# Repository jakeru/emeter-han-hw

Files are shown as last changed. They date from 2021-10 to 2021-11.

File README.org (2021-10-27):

#+TITLE: Use HAN port to get electricity usage

This is a software engineer playing with KiCad.

I have tried a few approaches but the one that is now active is the
e-meter-han-usb-c variant. It consists of a ESP32 and a USB-C connector as well
as a connector for the HAN port.

Note that this is still work in progress!

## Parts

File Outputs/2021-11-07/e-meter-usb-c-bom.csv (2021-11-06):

Comment | Designator | Footprint | LCSC Part #
10u Unpolarized capacitor | C1 | C_0603_1608Metric_Pad1.08x0.95mm_HandSolder | C19702
470p Unpolarized capacitor | C2 | C_0603_1608Metric_Pad1.08x0.95mm_HandSolder | C1620
2.2u Unpolarized capacitor | C3 | C_0603_1608Metric_Pad1.08x0.95mm_HandSolder | C23630
0.1u Unpolarized capacitor | C4,C6,C7 | C_0603_1608Metric_Pad1.08x0.95mm_HandSolder | C14663
22u Unpolarized capacitor | C5 | C_0603_1608Metric_Pad1.08x0.95mm_HandSolder | C59461
MDD-SS14 40V 1A Schottky Barrier Rectifier Diode, SMA(DO-214AC) | D1,D2 | D_SMA | C2480
LED Light emitting diode | D3,D4,D5 | LED_0603_1608Metric_Pad1.05x0.95mm_HandSolder | C2290
6P6C RJ connector, 6P6C (6 positions 6 connected), RJ12/RJ18/RJ25 | J1 | RJ12_Amphenol_54601 | C305981
USB_C_Receptacle_USB2.0 USB 2.0-only Type-C Receptacle connector | J2 | USB_C_Receptacle_HRO_TYPE-C-31-M-12 | C165948
S8050 0.7A Ic, 20V Vce, Low Voltage High Current NPN Transistor, TO-92 | Q1,Q3,Q4 | SOT-23 | C2150
4.7k Resistor, US symbol | R2 | R_0603_1608Metric_Pad0.98x0.95mm_HandSolder | C23162
68 Resistor, US symbol | R3,R7,R11 | R_0603_1608Metric_Pad0.98x0.95mm_HandSolder | C27592
10k Resistor, US symbol | R4,R5,R6,R10 | R_0603_1608Metric_Pad0.98x0.95mm_HandSolder | C25804
5.6k Resistor, US symbol | R8,R9 | R_0603_1608Metric_Pad0.98x0.95mm_HandSolder | C23189
SW_Push Push button switch, generic, two pins | SW1 | TE_Connectivity_FSM2JSMAA | C127509
ESP32-WROOM-32 RF Module, ESP32-D0WDQ6 SoC, Wi-Fi 802.11b/g/n, Bluetooth, BLE, 32-bit, 2.7-3.6V, onboard antenna, SMD | U2 | ESP32-WROOM-32 | C82899
CH340B (or C) USB serial converter, UART, SOIC-16 | U4 | SOIC-16_3.9x9.9mm_P1.27mm | C81010

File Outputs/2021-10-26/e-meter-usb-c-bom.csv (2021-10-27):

Comment | Designator | Footprint | LCSC Part #
10u Unpolarized capacitor | C1 | C_0603_1608Metric_Pad1.08x0.95mm_HandSolder
470p Unpolarized capacitor | C2 | C_0603_1608Metric_Pad1.08x0.95mm_HandSolder
2.2u Unpolarized capacitor | C3 | C_0603_1608Metric_Pad1.08x0.95mm_HandSolder
0.1u Unpolarized capacitor | C4,C6,C7 | C_0603_1608Metric_Pad1.08x0.95mm_HandSolder
22u Unpolarized capacitor | C5 | C_0603_1608Metric_Pad1.08x0.95mm_HandSolder
MDD-SS14 40V 1A Schottky Barrier Rectifier Diode, SMA(DO-214AC) | D1,D2 | D_SMA | C2480
LED Light emitting diode | D3,D4,D5 | LED_0201_0603Metric_Pad0.64x0.40mm_HandSolder | C2290
6P6C RJ connector, 6P6C (6 positions 6 connected), RJ12/RJ18/RJ25 | J1 | RJ12_Amphenol_54601 | C305981
USB_C_Receptacle_USB2.0 USB 2.0-only Type-C Receptacle connector | J2 | USB_C_Receptacle_HRO_TYPE-C-31-M-12 | C165948
S8050 0.7A Ic, 20V Vce, Low Voltage High Current NPN Transistor, TO-92 | Q1,Q3,Q4 | SOT-23 | C2150
4.7k Resistor, US symbol | R2 | R_0201_0603Metric_Pad0.64x0.40mm_HandSolder
60 Resistor, US symbol | R3,R7,R11 | R_0201_0603Metric_Pad0.64x0.40mm_HandSolder
10k Resistor, US symbol | R4,R5,R6,R10 | R_0201_0603Metric_Pad0.64x0.40mm_HandSolder
5.6k Resistor, US symbol | R8,R9 | R_0201_0603Metric_Pad0.64x0.40mm_HandSolder
SW_Push Push button switch, generic, two pins | SW1 | TE_Connectivity_FSM2JSMAA | C127509
ESP32-WROOM-32 RF Module, ESP32-D0WDQ6 SoC, Wi-Fi 802.11b/g/n, Bluetooth, BLE, 32-bit, 2.7-3.6V, onboard antenna, SMD | U2 | ESP32-WROOM-32 | C82899
CH340B (or C) USB serial converter, UART, SOIC-16 | U4 | SOIC-16_3.9x9.9mm_P1.27mm | C81010

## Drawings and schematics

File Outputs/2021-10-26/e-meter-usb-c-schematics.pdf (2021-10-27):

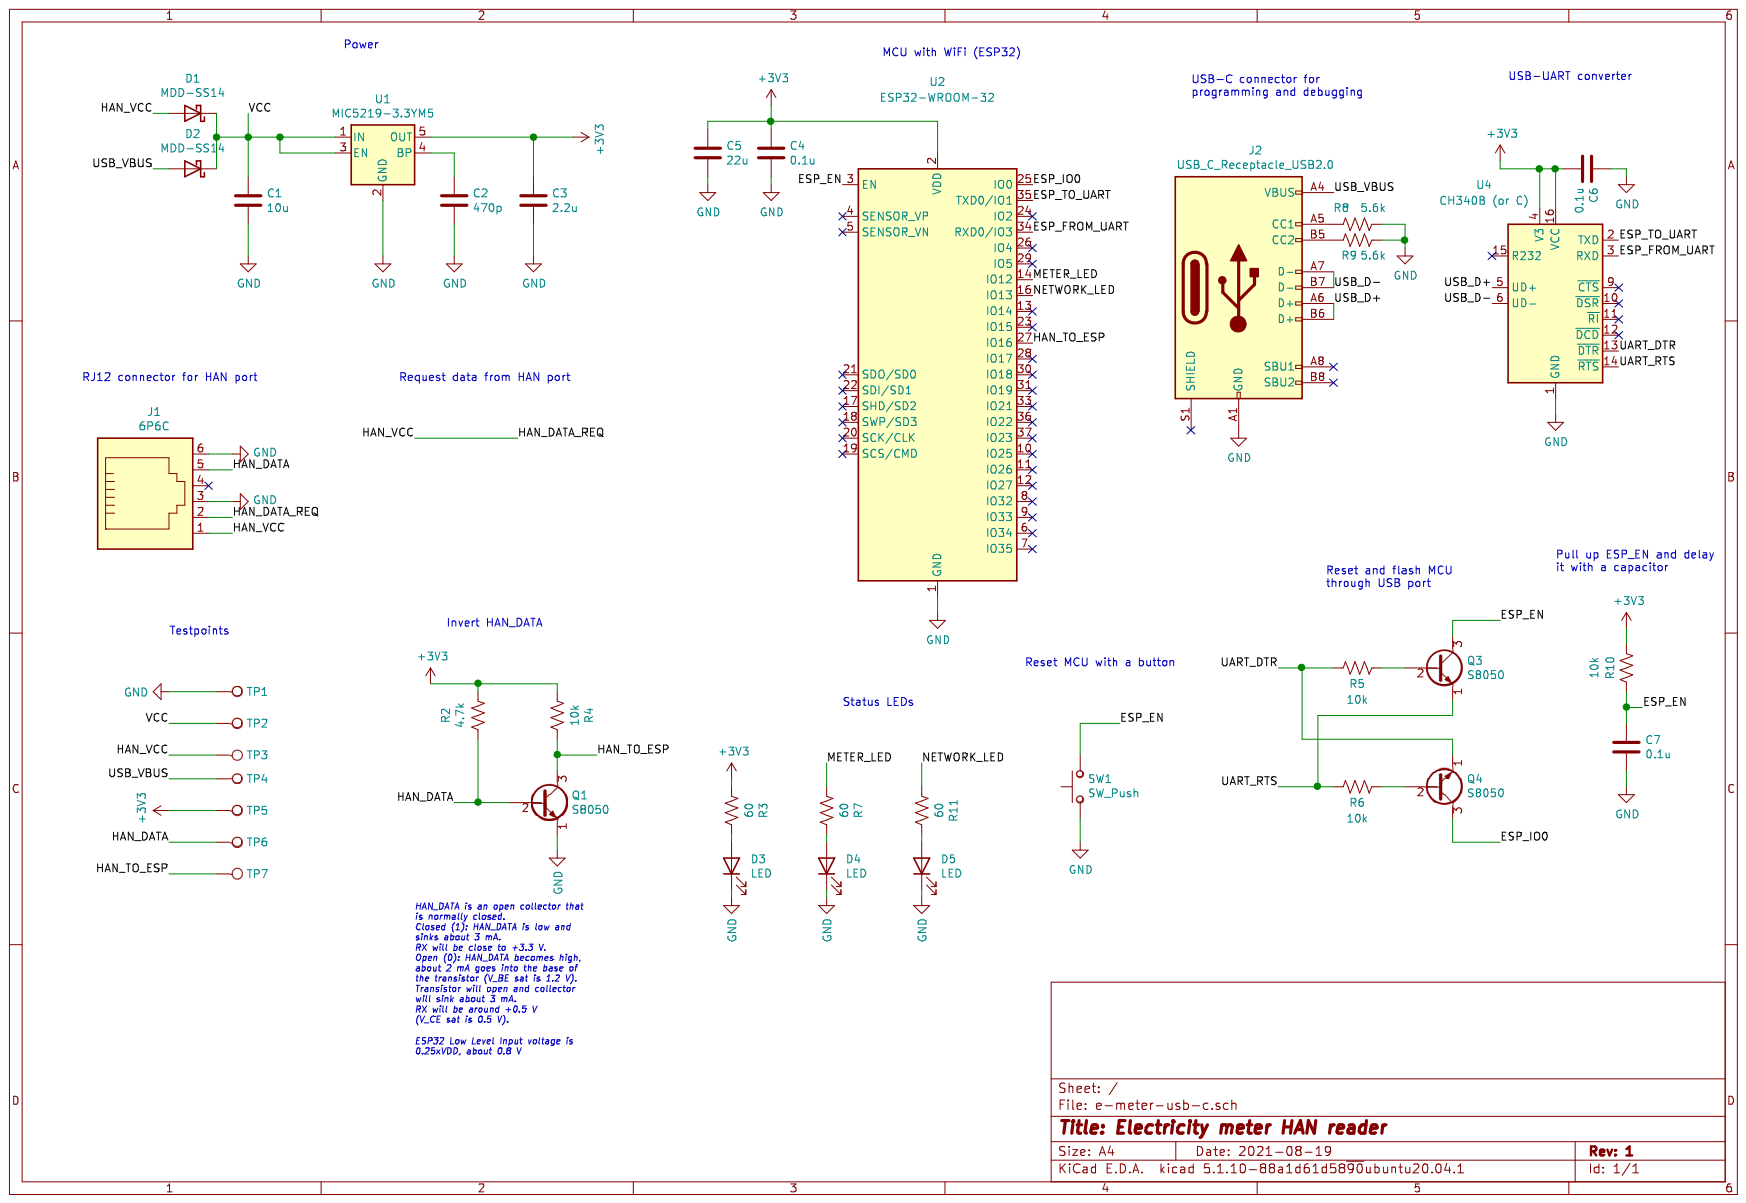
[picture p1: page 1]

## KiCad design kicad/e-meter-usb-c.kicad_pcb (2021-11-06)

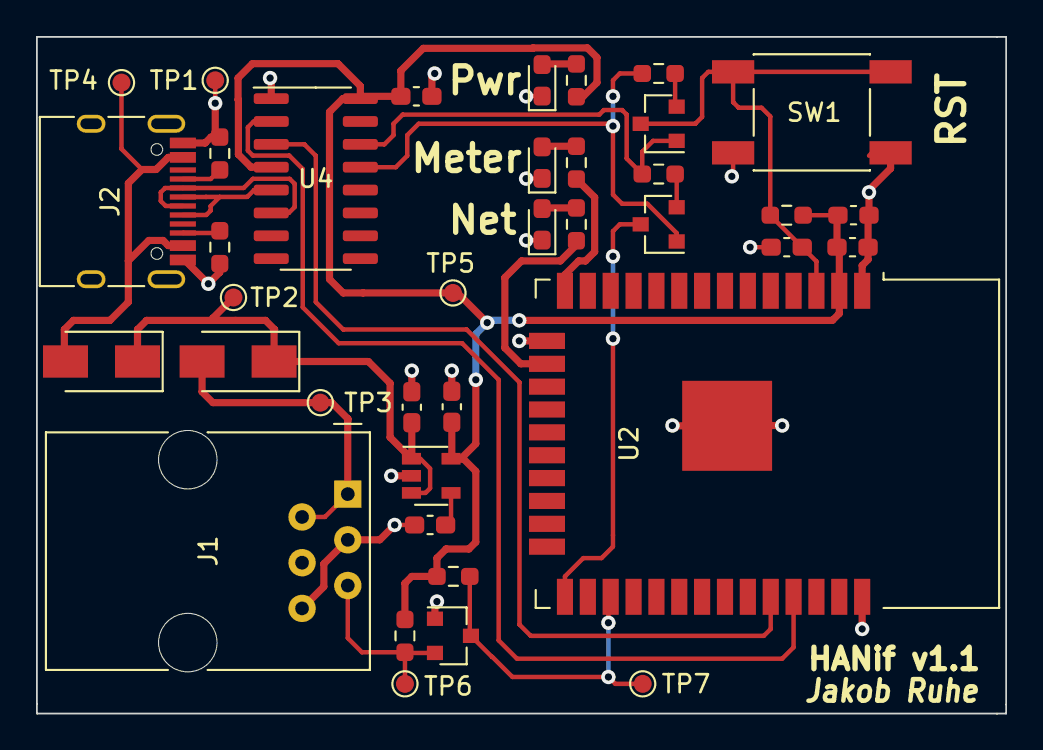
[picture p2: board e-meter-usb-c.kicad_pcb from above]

Board: 2 copper layers, 53.8 x 37.6 mm, 38 parts (0 on the bottom side), 25 nets.

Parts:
C1: 10u; C_0603_1608Metric_Pad1.08x0.95mm_HandSolder
C2: 470p; C_0603_1608Metric_Pad1.08x0.95mm_HandSolder
C3: 2.2u; C_0603_1608Metric_Pad1.08x0.95mm_HandSolder
C4, C6, C7: 0.1u; C_0603_1608Metric_Pad1.08x0.95mm_HandSolder
C5: 22u; C_0603_1608Metric_Pad1.08x0.95mm_HandSolder
D1, D2: MDD-SS14; D_SMA
D3, D4, D5: LED; LED_0603_1608Metric_Pad1.05x0.95mm_HandSolder
J1: 6P6C; RJ12_Amphenol_54601
J2: USB_C_Receptacle_USB2.0; USB_C_Receptacle_HRO_TYPE-C-31-M-12
Q1, Q3, Q4: S8050; SOT-23
R2: 4.7k; R_0603_1608Metric_Pad0.98x0.95mm_HandSolder
R3, R7, R11: 68; R_0603_1608Metric_Pad0.98x0.95mm_HandSolder
R4, R5, R6, R10: 10k; R_0603_1608Metric_Pad0.98x0.95mm_HandSolder
R8, R9: 5.6k; R_0603_1608Metric_Pad0.98x0.95mm_HandSolder
SW1: SW_Push; TE_Connectivity_FSM2JSMAA
TP1, TP2, TP3, TP4, TP5, TP6, TP7: TestPoint; TestPoint_Pad_D1.0mm
U1: MIC5219-3.3YM5; SOT-23-5
U2: ESP32-WROOM-32
U4: CH340B (or C); SOIC-16_3.9x9.9mm_P1.27mm

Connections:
+3V3: C3.1, C4.1, C5.1, C6.2, R2.1, R3.2, R4.2, R10.2, TP5.1, U1.5, U2.2, U4.4, U4.16
/ESP_EN: C7.1, Q3.3, R10.1, SW1.1, U2.3
/ESP_FROM_UART: U2.34, U4.3
/ESP_IO0: Q4.3, U2.25
/ESP_TO_UART: U2.35, U4.2
/HAN_DATA: J1.5, Q1.2, R2.2, TP6.1
/HAN_DATA_REQ: D1.2, J1.1, J1.2, TP3.1
/HAN_TO_ESP: Q1.3, R4.1, TP7.1, U2.27
/METER_LED: R7.2, U2.14
/NETWORK_LED: R11.2, U2.16
/UART_DTR: Q4.1, R5.2, U4.13
/UART_RTS: Q3.1, R6.2, U4.14
/USB_D+: J2.A6, J2.B6, U4.5
/USB_D-: J2.A7, J2.B7, U4.6
/USB_VBUS: D2.2, J2.A4, J2.A9, J2.B4, J2.B9, TP4.1
GND: C1.2, C2.2, C3.2, C4.2, C5.2, C6.1, C7.2, D3.1, D4.1, D5.1, J1.3, J1.6, J2.A1, J2.A12, J2.B1, J2.B12, Q1.1, R8.2, R9.2, SW1.2, TP1.1, U1.2, U2.1, U2.15, U2.38, U2.39, U4.1
unnamed: C2.1, U1.4
unnamed: D3.2, R3.1
unnamed: D4.2, R7.1
unnamed: D5.2, R11.1
unnamed: J2.A5, R8.1
unnamed: J2.B5, R9.1
unnamed: Q3.2, R5.1
unnamed: Q4.2, R6.1
VCC: C1.1, D1.1, D2.1, TP2.1, U1.1, U1.3

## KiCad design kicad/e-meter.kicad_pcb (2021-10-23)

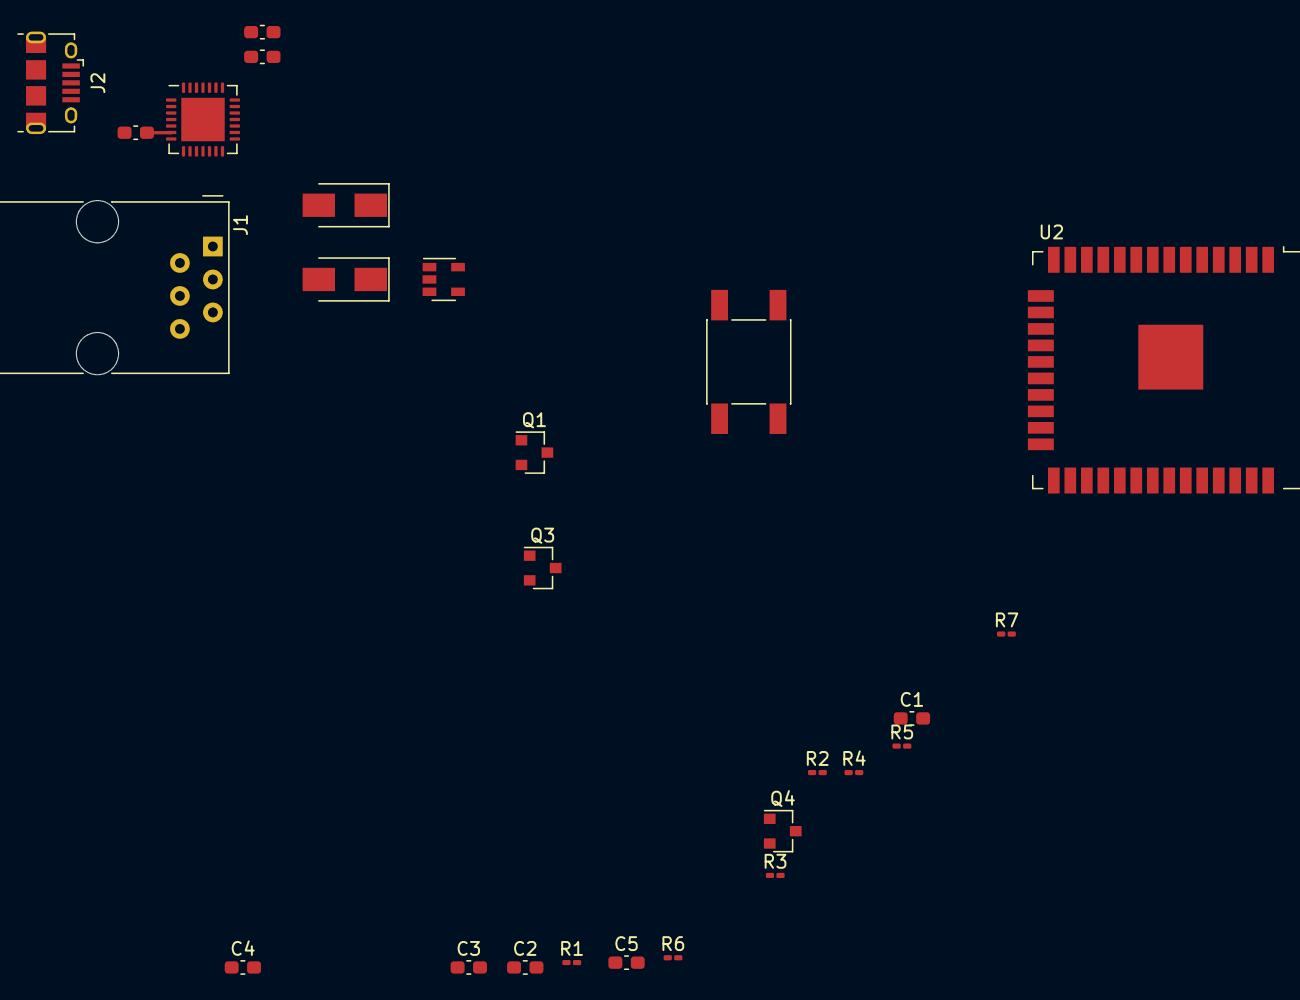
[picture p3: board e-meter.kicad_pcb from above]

Board: 2 copper layers, 26 parts (0 on the bottom side), 20 nets.

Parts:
C1, C2: 10u; C_0603_1608Metric_Pad1.08x0.95mm_HandSolder
C3, C5, C6: 1u; C_0603_1608Metric_Pad1.08x0.95mm_HandSolder
C4: 22u; C_0603_1608Metric_Pad1.08x0.95mm_HandSolder
C7, C8: 0.1u; C_0603_1608Metric_Pad1.08x0.95mm_HandSolder
D1, D2: MDD-SS14; D_SMA
J1: 6P6C; RJ12_Amphenol_54601
J2: USB_B_Micro; USB_Micro-B_Amphenol_10118194_Horizontal
Q1, Q3, Q4: S8050; SOT-23
R1: 100K; R_0201_0603Metric_Pad0.64x0.40mm_HandSolder
R2, R3, R4: 1K; R_0201_0603Metric_Pad0.64x0.40mm_HandSolder
R5, R6: 10k; R_0201_0603Metric_Pad0.64x0.40mm_HandSolder
R7: 10K; R_0201_0603Metric_Pad0.64x0.40mm_HandSolder
SW1: SW_Push; TE_Connectivity_FSM2JSMAA
U1: AP2112K-3.3; SOT-23-5
U2: ESP32-WROOM-32
U3: CP2102N-A01-GQFN28; QFN-28-1EP_5x5mm_P0.5mm_EP3.35x3.35mm

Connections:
+3V3: C2.1, C3.1, C4.1, R2.1, R4.2, R7.1, U1.5, U2.2
/CP_DTR: Q4.1, R5.2, U3.28
/CP_REGIN: C6.1, C8.1, D2.2, J2.1, U3.7, U3.8
/CP_RTS: Q3.1, R6.2, U3.24
/CP_RXD: U2.35, U3.25
/CP_TXD: U2.34, U3.26
/CP_VDD: C7.2, U3.6
/EN: C5.1, Q3.3, R7.2, SW1.2, U2.3
/HAN_DATA: J1.5, Q1.2, R2.2
/HAN_DATA_REQ: J1.2, R3.1
/HAN_VCC: D1.2, J1.1, R3.2
/IO0: Q4.3, U2.25
/RX: Q1.3, R4.1
/USB_DM: J2.2, U3.5
/USB_DP: J2.3, U3.4
/VCC: C1.1, D1.1, D2.1, R1.2, U1.1
GND: C1.2, C2.2, C3.2, C4.2, C5.2, C6.2, C7.1, C8.2, J1.3, J1.6, J2.5, Q1.1, SW1.1, U1.2, U2.1, U2.15, U2.38, U2.39, U3.3, U3.29
unnamed: Q3.2, R5.1
unnamed: Q4.2, R6.1
unnamed: R1.1, U1.3

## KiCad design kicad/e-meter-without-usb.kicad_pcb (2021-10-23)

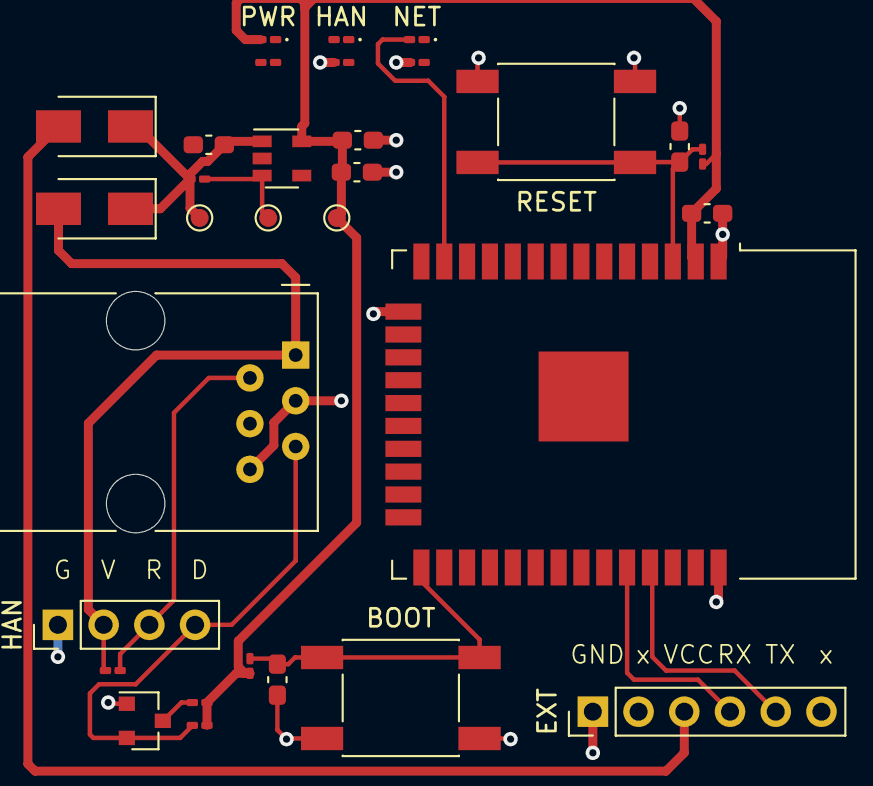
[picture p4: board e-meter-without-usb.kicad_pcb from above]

Board: 2 copper layers, 31 parts (0 on the bottom side), 18 nets.

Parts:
BOOT: SW_Push; TE_Connectivity_FSM2JSMAA
C1, C2: 10u; C_0603_1608Metric_Pad1.08x0.95mm_HandSolder
C3, C5, C6: 1u; C_0603_1608Metric_Pad1.08x0.95mm_HandSolder
C4: 22u; C_0603_1608Metric_Pad1.08x0.95mm_HandSolder
D1, D2: MDD-SS14; D_SMA
EXT: Conn_01x06; PinHeader_1x06_P2.54mm_Vertical
HAN: LED; LED_0201_0603Metric_Pad0.64x0.40mm_HandSolder
HAN#2: Conn_01x04; PinHeader_1x04_P2.54mm_Vertical
J1: 6P6C; RJ12_Amphenol_54601
NET: LED; LED_0201_0603Metric_Pad0.64x0.40mm_HandSolder
PWR: LED; LED_0201_0603Metric_Pad0.64x0.40mm_HandSolder
Q1: S8050; SOT-23
R1: 100K; R_0201_0603Metric_Pad0.64x0.40mm_HandSolder
R2, R3, R4: 1K; R_0201_0603Metric_Pad0.64x0.40mm_HandSolder
R5, R6, R9: 2K; R_0201_0603Metric_Pad0.64x0.40mm_HandSolder
R7, R8: 10K; R_0201_0603Metric_Pad0.64x0.40mm_HandSolder
RESET: SW_Push; TE_Connectivity_FSM2JSMAA
TP1, TP2, TP3: TestPoint; TestPoint_Pad_D1.0mm
U1: AP2112K-3.3; SOT-23-5
U2: ESP32-WROOM-32

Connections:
+3V3: C2.1, C3.1, C4.1, PWR.2, R2.1, R4.2, R7.1, R8.1, TP3.1, U1.5, U2.2
/BOOT: BOOT.2, C6.1, R8.2, U2.25
/EN: C5.1, R7.2, RESET.2, U2.3
/EXT_5V: D1.2, EXT.3
/EXT_FROM_ESP: EXT.5, U2.35
/EXT_TO_ESP: EXT.4, U2.34
/HAN_DATA: HAN#2.4, J1.5, Q1.2, R2.2
/HAN_DATA_REQ: HAN#2.3, J1.2, R3.1
/HAN_VCC: D2.2, HAN#2.2, J1.1, R3.2
/METER_LED: HAN.2, U2.23
/NETWORK_LED: NET.2, U2.13
/RX: Q1.3, R4.1
/VCC: C1.1, D1.1, D2.1, R1.2, TP1.1, U1.1
GND: BOOT.1, C1.2, C2.2, C3.2, C4.2, C5.2, C6.2, EXT.1, HAN#2.1, J1.3, J1.6, Q1.1, R5.1, R6.1, R9.1, RESET.1, U1.2, U2.1, U2.15, U2.38, U2.39
unnamed: PWR.1, R5.2
unnamed: NET.1, R6.2
unnamed: HAN.1, R9.2
unnamed: R1.1, TP2.1, U1.3

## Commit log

2021-10-23 Initial commit (WIP)
    [e-meter-plugin.sch, e-meter-usb-c.kicad_pcb, e-meter-usb-c.sch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]
2021-10-27 Change a few components
    I could not find the USB converter CH340C so went for CH340B instead.
    Same for the 3.3 Volt converter. I had to change it to another one, but
    even that one is not available at JLCPCB so I will have to solder it by
    hand.
    [e-meter-usb-c.kicad_pcb, e-meter-usb-c.sch]
2021-10-27 Add Output files 2021-10-26
    I never actually placed an order but I wanted to see the price of it and
    see if I remembered how to order things from JLCPCB.
    I noticed that a couple of components needs to be rotated and/or moved
    in order to be placed correctly.
    I should also add part numbers to the resistors and capacitors in order
    to have them mounted as well.
    [e-meter-usb-c-B_Cu.gbr, e-meter-usb-c-B_Mask.gbr, e-meter-usb-c-B_Paste.gbr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]
2021-11-06 Small updates, first order
    This was ordered from JLCPCB late yesterday evening.
    [e-meter-usb-c-B_Cu.gbl, e-meter-usb-c-B_Mask.gbs, e-meter-usb-c-B_Paste.gbp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]
2021-11-06 Fix resistors, LEDs and text
    I used a too small footprint for resistors and LEDs for the first order.
    This fixes that and also puts more text in the silk layer.
    [e-meter-usb-c-B_Cu.gbl, e-meter-usb-c-B_Mask.gbs, e-meter-usb-c-B_Paste.gbp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]
